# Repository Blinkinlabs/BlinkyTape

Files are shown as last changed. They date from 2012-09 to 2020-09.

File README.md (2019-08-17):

# BlinkyTape

BlinkyTape Photo

BlinkyTape is a one meter long, full-color light tape with 60 independent RGB LEDs controlled by our custom light processor. Power and communications are provided by a built-in micro-USB connector. An on-board button allows for simple interactions such as choosing between effects.

BlinkyTape is flexible, so you can easily integrate it into any shape your project needs. BlinkyTape also comes enclosed in weatherproof silicone, so it's suitable for outdoor use!

This GitHub repository contains the design files for the BlinkyTape controller, as well as the production test files.

More information about the BlinkyTape is available here: [http://blinkinlabs.com/blinkytape/](http://blinkinlabs.com/blinkytape/)

# I want one!

Cool! BlinkyTape is available in [our store](http://blinkinlabs.myshopify.com/products/blinkytape-basic), as well as through many fine distributors.

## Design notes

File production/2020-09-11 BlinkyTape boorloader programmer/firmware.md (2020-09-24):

Script for programming BlinkyTape firmware, using an Arduino as an ICSP.

Blinkytape firmware from PatternPaint: f31ba217fc51956d9388c4821eff59d83c6dc491
Bootloader from BlinkyTape: 968b2e03a9b3f808e57ad69727cdd8145f4d0792

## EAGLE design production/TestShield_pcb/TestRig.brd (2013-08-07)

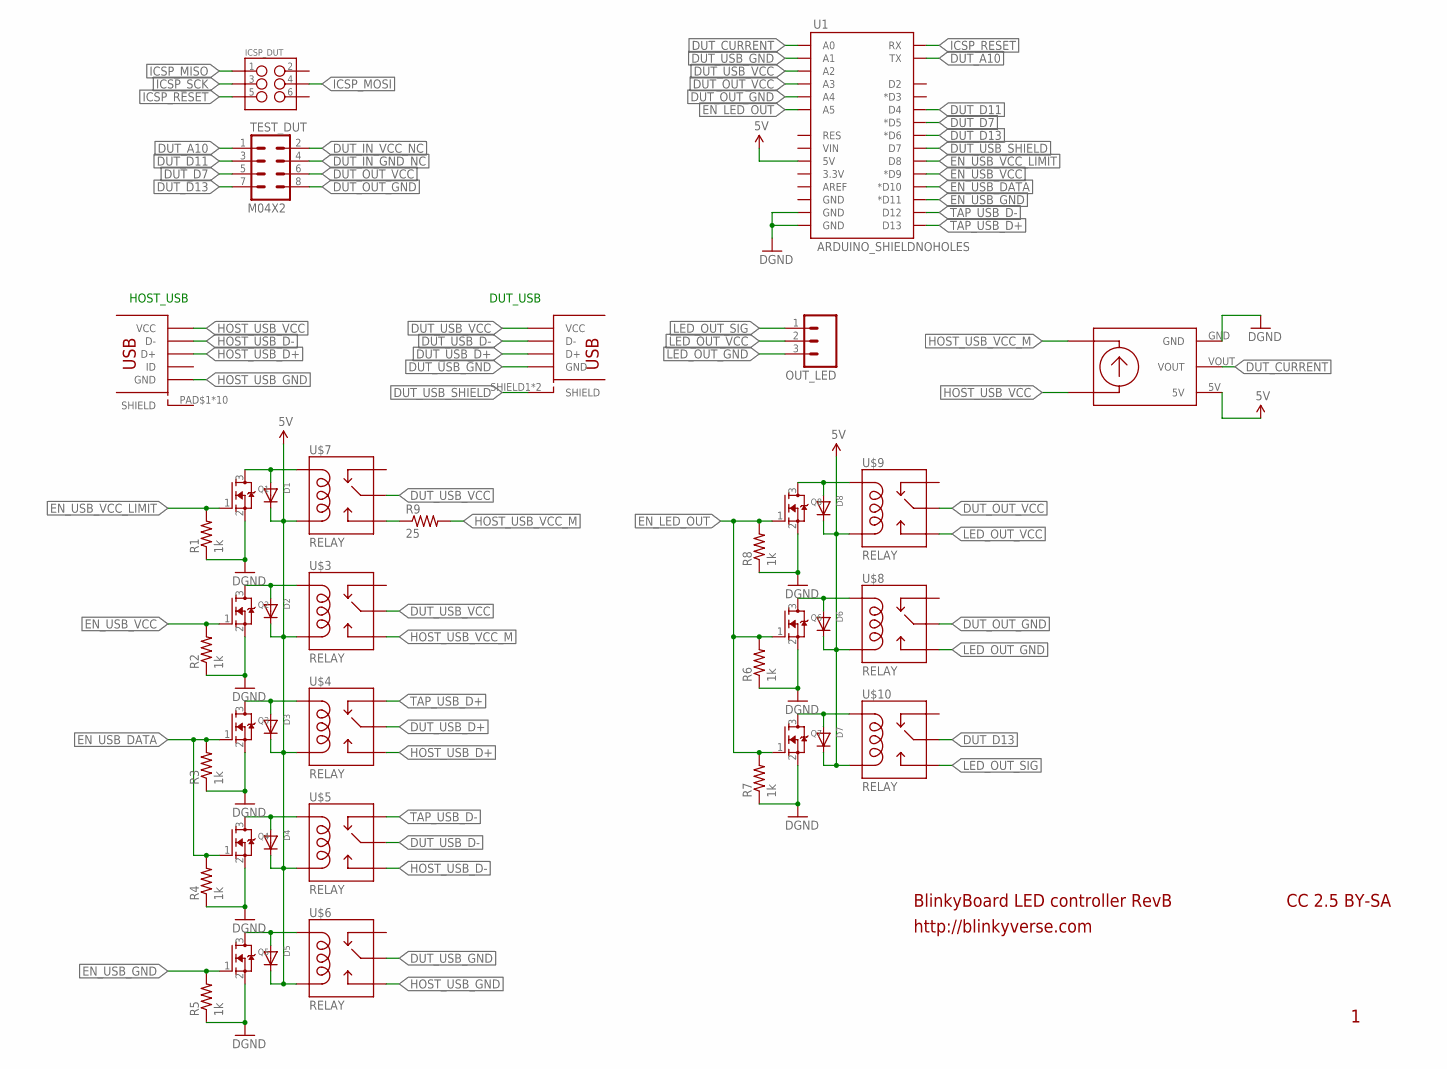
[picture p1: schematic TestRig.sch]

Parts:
D1, D2, D3, D4, D5, D6, D7, D8: DIODESOD-523; SOD-523
ICSP_DUT: M03X2NO_SILK; 2X3-NS
OUT_LED: M03PTH; 1X03
Q1, Q2, Q3, Q4, Q5, Q6, Q7, Q8: MOSFET-NREFLOW; SOT23
R1, R2, R3, R4, R5, R6, R7, R8: 1k; R0603
R9: 25; R1210
TEST_DUT: M04X2; 2X4
U1: ARDUINO_SHIELDNOHOLES; DUEMILANOVE_SHIELD_NOHOLES
U$1: USB; USB_A_FEMALE_NOSILK_SHIELD
U$2: MICRO_USBSMT+THRUHULE; MICRO_USB_FCI_THRUHOLE
U$3, U$4, U$5, U$6, U$7, U$8, U$9, U$10: RELAY; RELAY_HK23F-5V
U$11: SPARKFUN_ACS712

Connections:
5V: D1.K (C), D2.K (C), D3.K (C), D4.K (C), D5.K (C), D6.K (C), D7.K (C), D8.K (C), U1.5V, U$3.P$5 (COIL2), U$4.P$5 (COIL2), U$5.P$5 (COIL2), U$6.P$5 (COIL2), U$7.P$5 (COIL2), U$8.P$5 (COIL2), U$9.P$5 (COIL2), U$10.P$5 (COIL2), U$11.5V
DUT_A10: TEST_DUT.1, U1.TX
DUT_CURRENT: U1.A0, U$11.VOUT
DUT_D7: TEST_DUT.5, U1.D5 (*D5)
DUT_D11: TEST_DUT.3, U1.D4
DUT_D13: TEST_DUT.7, U1.D6 (*D6), U$10.P$1 (MAIN), U$10.P$6 (MAIN)
DUT_IN_GND_NC: TEST_DUT.4
DUT_IN_VCC_NC: TEST_DUT.2
DUT_OUT_GND: TEST_DUT.8, U1.A4, U$8.P$1 (MAIN), U$8.P$6 (MAIN)
DUT_OUT_VCC: TEST_DUT.6, U1.A3, U$9.P$1 (MAIN), U$9.P$6 (MAIN)
DUT_USB_D+: U$1.D+, U$4.P$1 (MAIN), U$4.P$6 (MAIN)
DUT_USB_D-: U$1.D-, U$5.P$1 (MAIN), U$5.P$6 (MAIN)
DUT_USB_GND: U1.A1, U$1.GND, U$6.P$1 (MAIN), U$6.P$6 (MAIN)
DUT_USB_SHIELD: U1.D7, U$1.SHIELD1 (SHIELD), U$1.SHIELD2 (SHIELD)
DUT_USB_VCC: U1.A2, U$1.VBUS (VCC), U$3.P$1 (MAIN), U$3.P$6 (MAIN), U$7.P$1 (MAIN), U$7.P$6 (MAIN)
EN_LED_OUT: Q6.1 (G), Q7.1 (G), Q8.1 (G), R6.2, R7.2, R8.2, U1.A5
EN_USB_DATA: Q3.1 (G), Q4.1 (G), R3.2, R4.2, U1.D10 (*D10)
EN_USB_GND: Q5.1 (G), R5.2, U1.D11 (*D11)
EN_USB_VCC: Q2.1 (G), R2.2, U1.D9 (*D9)
EN_USB_VCC_LIMIT: Q1.1 (G), R1.2, U1.D8
GND: Q1.2 (S), Q2.2 (S), Q3.2 (S), Q4.2 (S), Q5.2 (S), Q6.2 (S), Q7.2 (S), Q8.2 (S), R1.1, R2.1, R3.1, R4.1, R5.1, R6.1, R7.1, R8.1, U1.GND@0 (GND), U1.GND@1 (GND), U$11.GND
HOST_USB_D+: U$2.PIN$3 (D+), U$4.P$3 (NO)
HOST_USB_D-: U$2.PIN$2 (D-), U$5.P$3 (NO)
HOST_USB_GND: U$2.PIN$5 (GND), U$6.P$3 (NO)
HOST_USB_VCC: U$2.PIN$1 (VCC), U$11.IP-
HOST_USB_VCC_M: R9.2, U$3.P$3 (NO), U$11.IP+
ICSP_MISO: ICSP_DUT.1
ICSP_MOSI: ICSP_DUT.4
ICSP_RESET: ICSP_DUT.5, U1.RX
ICSP_SCK: ICSP_DUT.3
LED_OUT_GND: OUT_LED.3, U$8.P$3 (NO)
LED_OUT_SIG: OUT_LED.1, U$10.P$3 (NO)
LED_OUT_VCC: OUT_LED.2, U$9.P$3 (NO)
unnamed: R9.1, U$7.P$3 (NO)
unnamed: D1.A, Q1.3 (D), U$7.P$2 (COIL1)
unnamed: D2.A, Q2.3 (D), U$3.P$2 (COIL1)
unnamed: D3.A, Q3.3 (D), U$4.P$2 (COIL1)
unnamed: D4.A, Q4.3 (D), U$5.P$2 (COIL1)
unnamed: D5.A, Q5.3 (D), U$6.P$2 (COIL1)
unnamed: D6.A, Q6.3 (D), U$8.P$2 (COIL1)
unnamed: D7.A, Q7.3 (D), U$10.P$2 (COIL1)
unnamed: D8.A, Q8.3 (D), U$9.P$2 (COIL1)
TAP_USB_D+: U1.D13, U$4.P$4 (NC)
TAP_USB_D-: U1.D12, U$5.P$4 (NC)

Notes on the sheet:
BlinkyBoard LED controller RevB
http://blinkyverse.com
CC 2.5 BY-SA
DUT_USB
HOST_USB

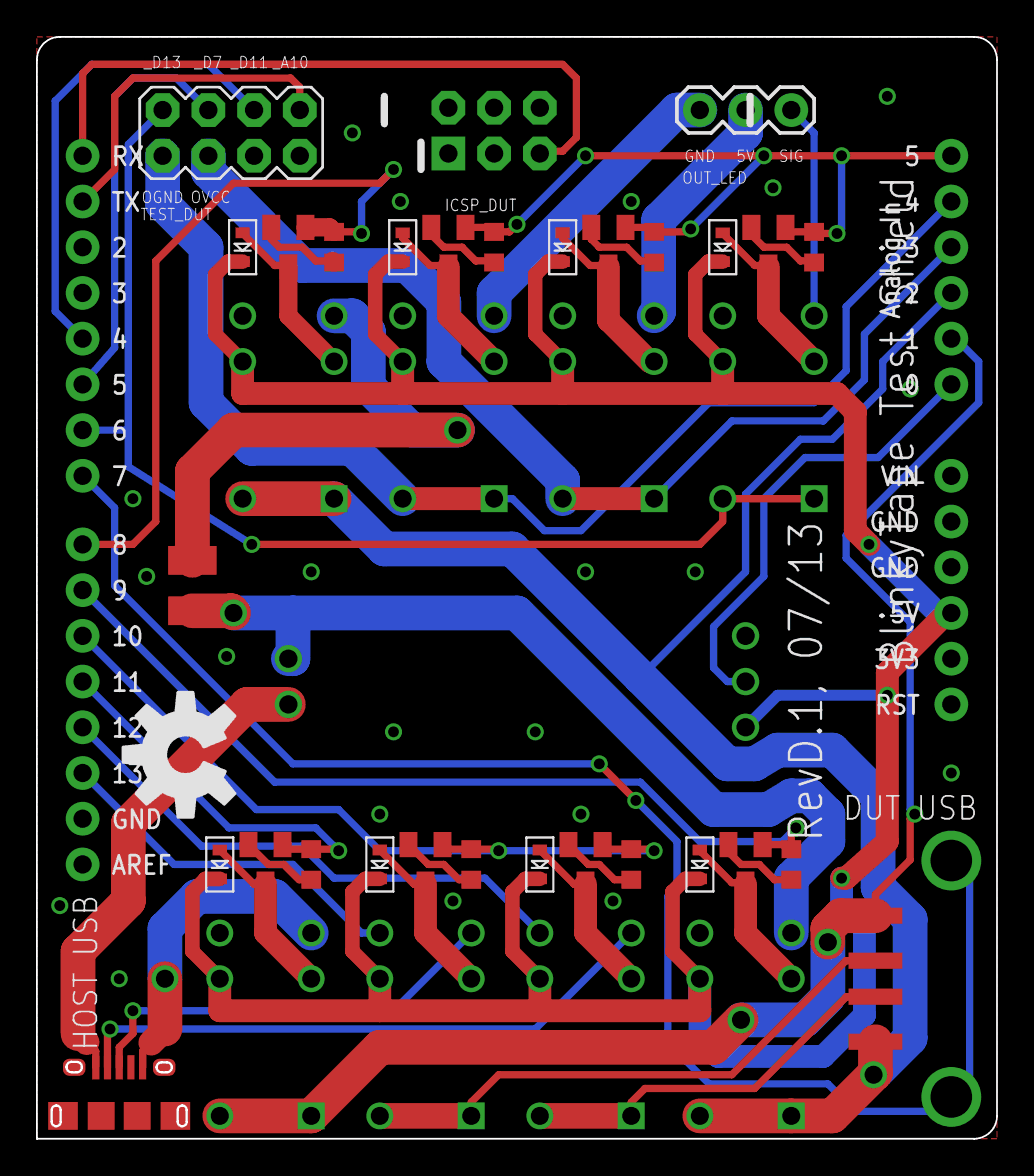
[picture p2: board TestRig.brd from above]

Board: 2 copper layers, 53.3 x 61.2 mm, 41 parts (0 on the bottom side), 39 nets.

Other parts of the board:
U$12: OSHW-LOGO-L

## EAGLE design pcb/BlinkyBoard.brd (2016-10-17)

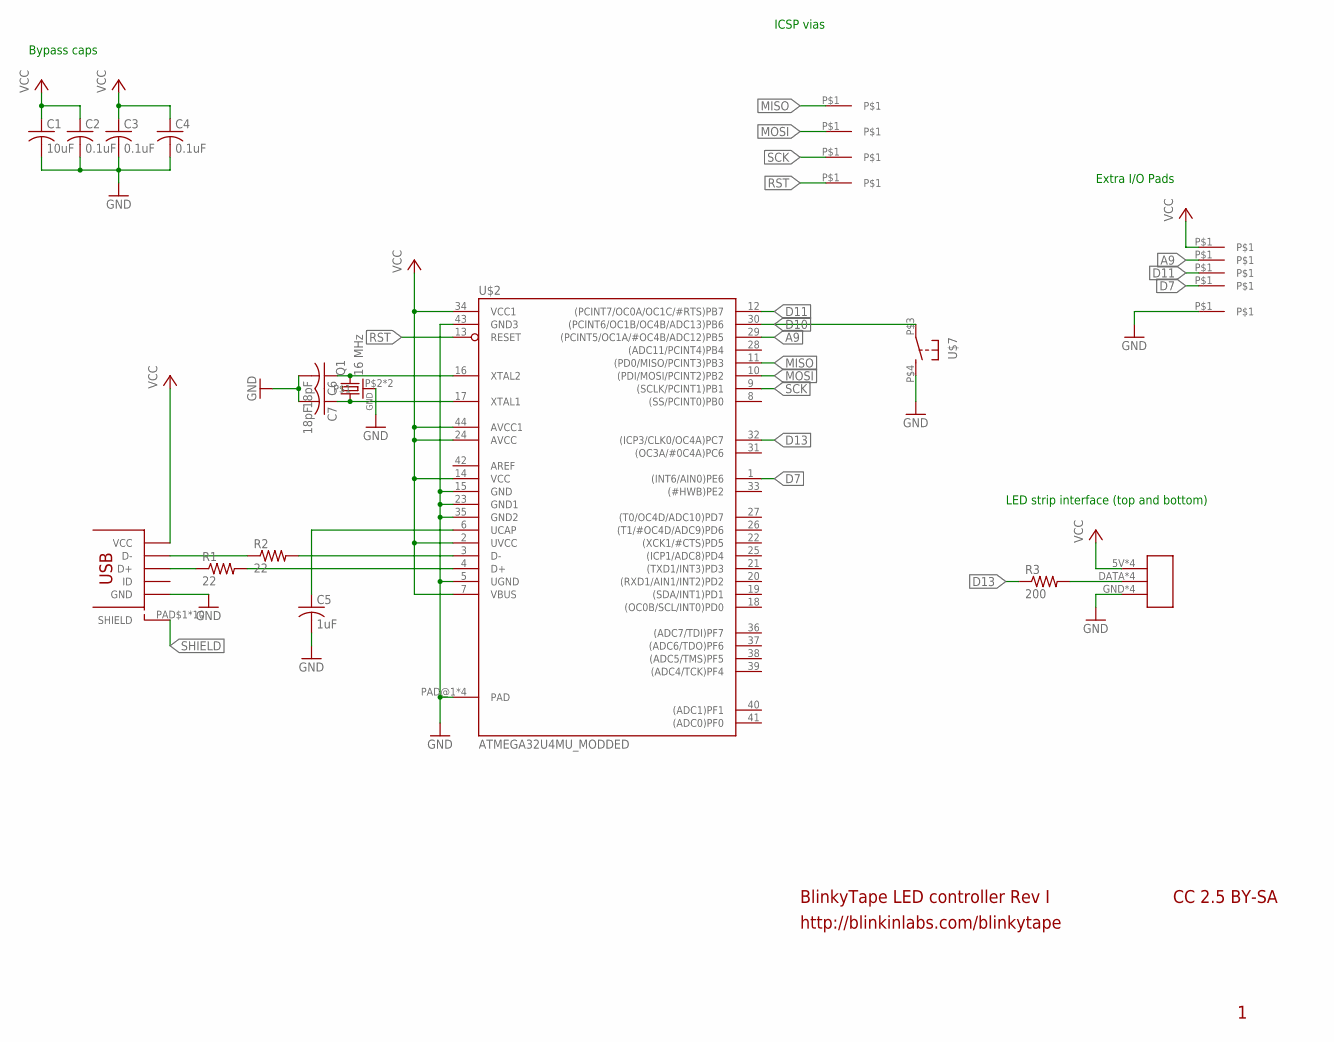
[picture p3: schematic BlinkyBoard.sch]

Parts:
C1: 10uF; C0603K
C2, C3, C4: 0.1uF; CAP_0402_KEMET_MEDIAN
C5: 1uF; CAP_0402_KEMET_MEDIAN
C6, C7: 18pF; CAP_0402_KEMET_MEDIAN
Q1: 16 MHz; CRSYTAL_2520
R1, R2: 22; RES_0402_KEMET_MEDIAN
R3: 200; RES_0402_KEMET_MEDIAN
U$1, U$3, U$5, U$6: TEST_PAD_SMT; TEST_PAD_1MM
U$2: ATMEGA32U4MU_MODDED; QFN44ML_7X7_LONGLEADS_MOD
U$4: USB_MICROSMT+THRUHULE; USB_MICRO_THRUHOLE
U$7: BUTTON_MOMENTARY; BUTTON_2P_SMD
U$9: WS2812B_CONNECTOR
U$10, U$11, U$12, U$13, U$14: TEST_PAD_SMT

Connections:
A9: U$2.29 ((PCINT5/OC1A/#OC4B/ADC12)PB5), U$11.P$1
AREF: U$2.42 (AREF)
D7: U$2.1 ((INT6/AIN0)PE6), U$10.P$1
D10: U$2.30 ((PCINT6/OC1B/OC4B/ADC13)PB6), U$7.P$3
D11: U$2.12 ((PCINT7/OC0A/OC1C/#RTS)PB7), U$14.P$1
D13: R3.P$1 (1), U$2.32 ((ICP3/CLK0/OC4A)PC7)
D+: R1.P$2 (2), U$2.4 (D+)
D+_IN: R1.P$1 (1), U$4.PIN$3 (D+)
D-: R2.P$2 (2), U$2.3 (D-)
D-_IN: R2.P$1 (1), U$4.PIN$2 (D-)
GND: C1.2, C2.P$2 (2), C3.P$2 (2), C4.P$2 (2), C5.P$2 (2), C6.P$2 (2), C7.P$2 (2), Q1.P$2, Q1.P$4, U$2.5 (UGND), U$2.15 (GND), U$2.23 (GND1), U$2.35 (GND2), U$2.43 (GND3), U$2.PAD@1 (PAD), U$2.PAD@4 (PAD), U$2.PAD@13 (PAD), U$2.PAD@16 (PAD), U$4.PIN$5 (GND), U$7.P$4 (S), U$9.GND, U$9.GND1 (GND), U$9.GND_1 (GND), U$9.GND_2 (GND), U$13.P$1
LED_DATA: R3.P$2 (2), U$9.DATA, U$9.DATA1 (DATA), U$9.DATA_1 (DATA), U$9.DATA_2 (DATA)
MISO: U$1.P$1, U$2.11 ((PD0/MISO/PCINT3)PB3)
MOSI: U$2.10 ((PDI/MOSI/PCINT2)PB2), U$3.P$1
unnamed: C5.P$1 (1), U$2.6 (UCAP)
unnamed: C6.P$1 (1), Q1.P$3 (2), U$2.16 (XTAL2)
unnamed: C7.P$1 (1), Q1.P$1 (1), U$2.17 (XTAL1)
RST: U$2.13 (RESET), U$6.P$1
SCK: U$2.9 ((SCLK/PCINT1)PB1), U$5.P$1
SHIELD: U$4.PAD$1 (SHIELD), U$4.PAD$2 (SHIELD), U$4.PAD$3 (SHIELD), U$4.PAD$4 (SHIELD), U$4.PAD$5 (SHIELD), U$4.PAD$6 (SHIELD), U$4.PAD$7 (SHIELD), U$4.PAD$8 (SHIELD), U$4.PAD$9 (SHIELD), U$4.PAD$10 (SHIELD)
VCC: C1.1, C2.P$1 (1), C3.P$1 (1), C4.P$1 (1), U$2.2 (UVCC), U$2.7 (VBUS), U$2.14 (VCC), U$2.24 (AVCC), U$2.34 (VCC1), U$2.44 (AVCC1), U$4.PIN$1 (VCC), U$9.5V, U$9.5V1 (5V), U$9.5V_1 (5V), U$9.5V_2 (5V), U$12.P$1

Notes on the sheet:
BlinkyTape LED controller Rev I
http://blinkinlabs.com/blinkytape
CC 2.5 BY-SA
Bypass caps
ICSP vias
Extra I/O Pads
LED strip interface (top and bottom)

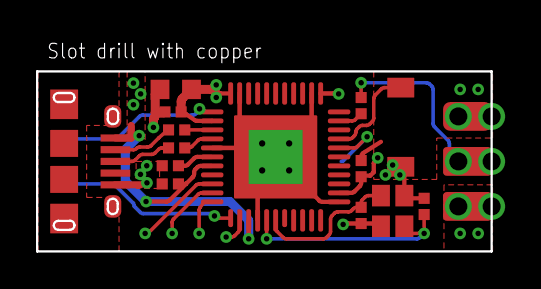
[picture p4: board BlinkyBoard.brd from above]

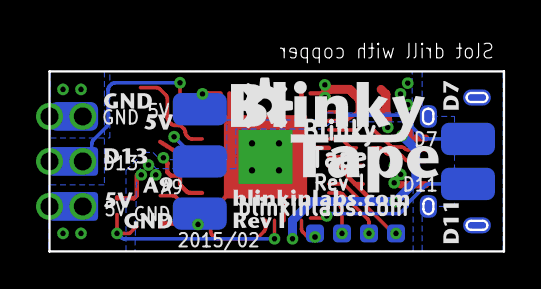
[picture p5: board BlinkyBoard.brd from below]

Board: 2 copper layers, 25.2 x 10.0 mm, 25 parts (11 on the bottom side), 20 nets.

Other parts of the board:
U$15: OSHW-LOGO-S

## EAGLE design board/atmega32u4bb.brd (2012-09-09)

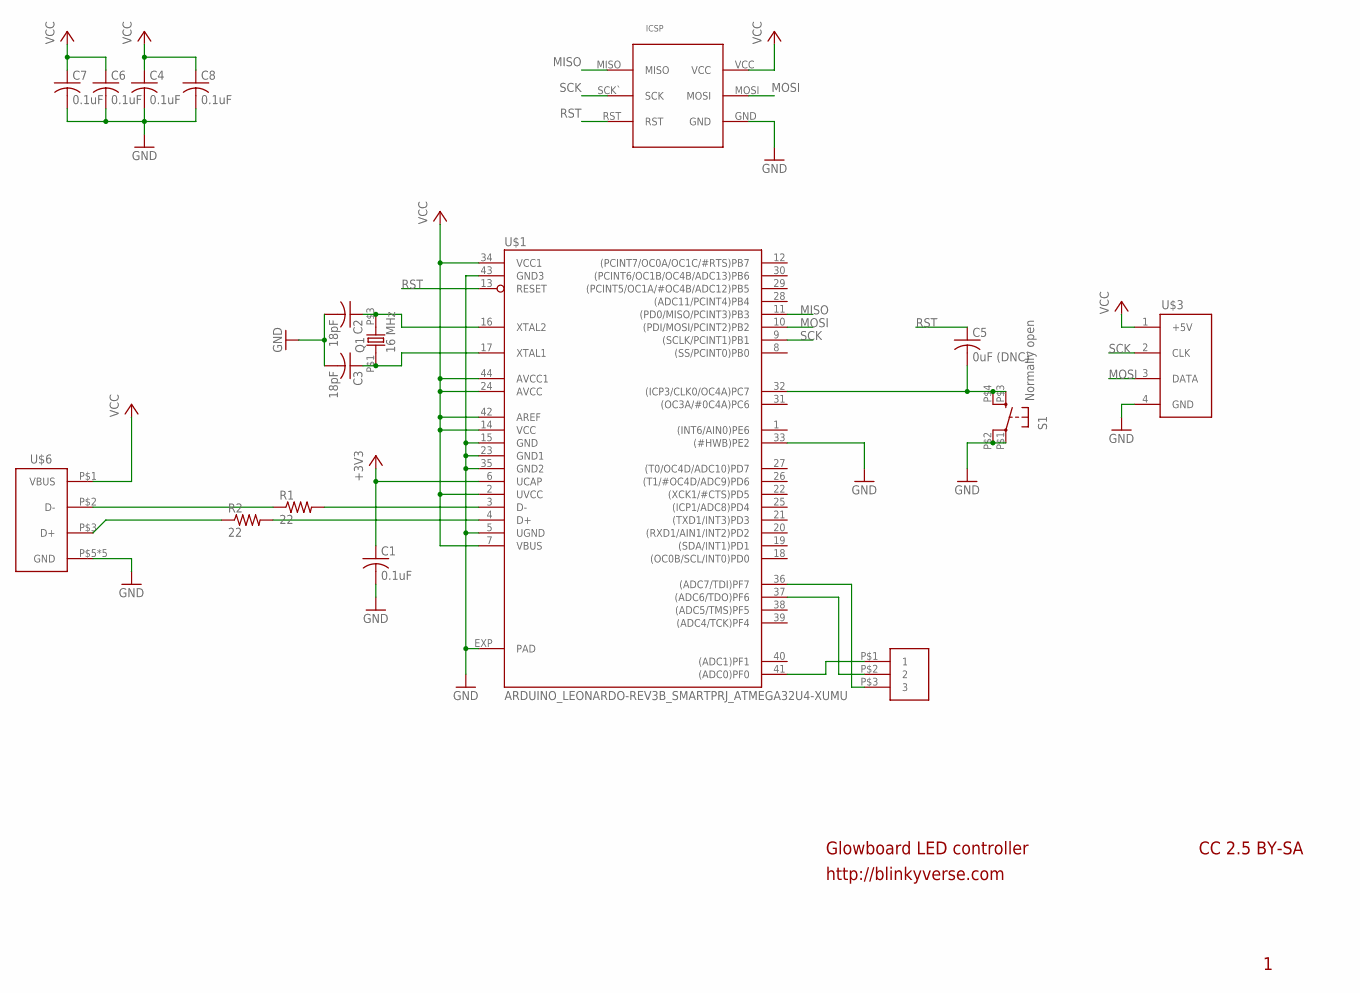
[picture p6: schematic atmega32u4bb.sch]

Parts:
C1, C4, C6, C7, C8: 0.1uF; C0805K
C2, C3: 18pF; C0805K
C5: 0uF (DNC); C0805K
Q1: 16 MHz; ABMM2_CRYSTAL
R1, R2: 22; R0805
S1: Normally open; GLOWBOARD_KMR211G_SWITCH
U$1: ARDUINO_LEONARDO-REV3B_SMARTPRJ_ATMEGA32U4-XUMU; ARDUINO_LEONARDO-REV3B_SMARTPRJ_QFN44ML7X7
U$3: GLOWBOARD_PAD_CONNECTION
U$4: GLOWBOARD_ICSP; GLOWBOARD_ICSP_PADS
U$5: GLOWBOARD_EXPANSION_HEADER
U$6: GLOWBOARD_MINI_USB; GLOWBOARD_MINI_USB_PADS

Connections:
+3V3: C1.1, U$1.6 (UCAP)
GND: C1.2, C2.2, C3.2, C4.2, C6.2, C7.2, C8.2, S1.P$1, S1.P$2 (P1), U$1.5 (UGND), U$1.15 (GND), U$1.23 (GND1), U$1.33 ((#HWB)PE2), U$1.35 (GND2), U$1.43 (GND3), U$1.EXP (PAD), U$3.4 (GND), U$4.GND, U$6.P$5 (GND), U$6.P$6 (GND), U$6.P$7 (GND), U$6.P$8 (GND), U$6.P$9 (GND)
MISO: U$1.11 ((PD0/MISO/PCINT3)PB3), U$4.MISO
MOSI: U$1.10 ((PDI/MOSI/PCINT2)PB2), U$3.3 (DATA), U$4.MOSI
unnamed: U$1.41 ((ADC0)PF0), U$5.P$1 (1)
unnamed: R2.1, U$6.P$3 (D+)
unnamed: R1.2, U$1.3 (D-)
unnamed: R2.2, U$1.4 (D+)
unnamed: R1.1, U$6.P$2 (D-)
unnamed: U$1.37 ((ADC6/TDO)PF6), U$5.P$2 (2)
unnamed: U$1.36 ((ADC7/TDI)PF7), U$5.P$3 (3)
unnamed: C2.1, Q1.P$3 (2), U$1.16 (XTAL2)
unnamed: C3.1, Q1.P$1 (1), U$1.17 (XTAL1)
unnamed: C5.2, S1.P$3 (S), S1.P$4 (S1), U$1.32 ((ICP3/CLK0/OC4A)PC7)
RST: C5.1, U$1.13 (RESET), U$4.RST
SCK: U$1.9 ((SCLK/PCINT1)PB1), U$3.2 (CLK), U$4.SCK` (SCK)
VCC: C4.1, C6.1, C7.1, C8.1, U$1.2 (UVCC), U$1.7 (VBUS), U$1.14 (VCC), U$1.24 (AVCC), U$1.34 (VCC1), U$1.42 (AREF), U$1.44 (AVCC1), U$3.1 (+5V), U$4.VCC, U$6.P$1 (VBUS)

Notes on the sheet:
Glowboard LED controller
http://blinkyverse.com
CC 2.5 BY-SA

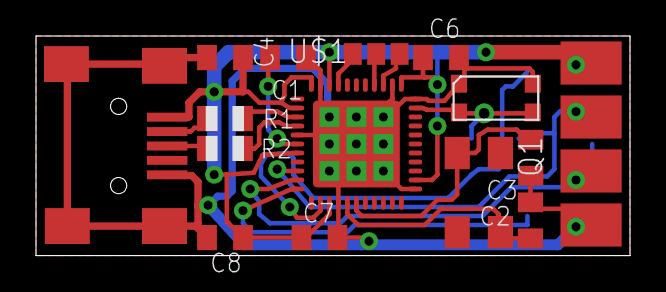
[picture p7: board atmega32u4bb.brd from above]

Board: 2 copper layers, 33.0 x 12.2 mm, 17 parts (1 on the bottom side), 17 nets.

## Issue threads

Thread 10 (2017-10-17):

External flash idea

dunk8888, 2017-10-17:
Hi,ime just wondering if its possible to have the blinky tape store the patterns into an external winbond flash unit,and if so would it be much work to implement ? Ime thinking this would be an idea many users would like,that way we can store many patterns to memory.Maybe a good idea to add an example for users who make there own BlinkTape version,ive made a few my self.

cibomahto, 2017-10-17:
We have something similar working in the EightByEight badge, which uses the flash chip built into the ESP8266 to store patterns:
https://github.com/Blinkinlabs/eightbyeight

The biggest issue with adding it to the current BlinkyTape is that the Atmega32u4 needs 5V to run at 16MHz speed, but basically all serial flash chips require a 3.3V interface. We've made some prototypes using an ARM part to replace the Atmega, and can fit the whole thing into the same size board as the blinkytape... but it still needs some development before we can release.

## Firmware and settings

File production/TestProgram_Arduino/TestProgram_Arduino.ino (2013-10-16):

// BlinkyTape Test Rig controller + ISP
// 
// 
// Based off of:
// 
// ArduinoISP version 04m3
// Copyright (c) 2008-2011 Randall Bohn
// If you require a license, see 
//     http://www.opensource.org/licenses/bsd-license.php
//
// This sketch turns the Arduino into a AVRISP
// using the following arduino pins:
//
// pin name:    BlinkyTape:
// slave reset: 0
// MOSI:        (MOSI, ICSP header)
// MISO:        (MISO, ICSP header)
// SCK:         (SCK, ICSP header)
//
// Put an LED (with resistor) on the following pins:
// X: Heartbeat   - shows the programmer is running=
// 0: Error       - Lights up if something goes wrong (use red if that makes sense)
// 1: Programming - In communication with the slave
//
// 6 August 2013 Matt Mets
// -Replace the analog current measurement with an INA219 courtesy Adafruit
// -Remove all LEDs (really no spare pins!)
// -move target reset pin to 0
//
// 7 July 2013 Matt Mets
// -Disable 'heartbeat' (no free pins!), move error, programming to pins 0 and 1.
// -Move target reset to pin 2.
// -Add 0x21 command for BlinkyTape Test rig functionality (!)
//
// 23 July 2011 Randall Bohn
// -Address Arduino issue 509 :: Portability of ArduinoISP
// http://code.google.com/p/arduino/issues/detail?id=509
//
// October 2010 by Randall Bohn
// - Write to EEPROM > 256 bytes
// - Better use of LEDs:
// -- Flash LED_PMODE on each flash commit
// -- Flash LED_PMODE while writing EEPROM (both give visual feedback of writing progress)
// - Light LED_ERR whenever we hit a STK_NOSYNC. Turn it off when back in sync.
// - Use pins_arduino.h (should also work on Arduino Mega)
//
// October 2009 by David A. Mellis
// - Added support for the read signature command
// 
// February 2009 by Randall Bohn
// - Added support for writing to EEPROM (what took so long?)
// Windows users should consider WinAVR's avrdude instead of the
// avrdude included with Arduino software.
//
// January 2008 by Randall Bohn
// - Thanks to Amplificar for helping me with the STK500 protocol
// - The AVRISP/STK500 (mk I) protocol is used in the arduino bootloader
// - The SPI functions herein were developed for the AVR910_ARD programmer 
// - More information at http://code.google.com/p/mega-isp

#include "pins_arduino.h"
#include <Wire.h>
#include <Adafruit_INA219.h>

Adafruit_INA219 ina219;

#define RESET     0

//#define LED_HB    0
//#define LED_ERR   0
//#define LED_PMODE 1
//#define PROG_FLICKER true

#define HWVER 2
#define SWMAJ 1
#define SWMIN 18

// STK Definitions
#define STK_OK      0x10
#define STK_FAILED  0x11
#define STK_UNKNOWN 0x12
#define STK_INSYNC  0x14
#define STK_NOSYNC  0x15
#define CRC_EOP     0x20 //ok it is a space...

void pulse(int pin, int times);

void setup() {
  Serial.begin(19200);
//  pinMode(LED_PMODE, OUTPUT);
//  pulse(LED_PMODE, 2);
//  pinMode(LED_ERR, OUTPUT);
//  pulse(LED_ERR, 2);
//  pinMode(LED_HB, OUTPUT);
//  pulse(LED_HB, 2);

  ina219.begin();
}

int error=0;
int pmode=0;
// address for reading and writing, set by 'U' command
int here;
uint8_t buff[256]; // global block storage

#define beget16(addr) (*addr * 256 + *(addr+1) )
typedef struct param {
  uint8_t devicecode;
  uint8_t revision;
  uint8_t progtype;
  uint8_t parmode;
  uint8_t polling;
  uint8_t selftimed;
  uint8_t lockbytes;
  uint8_t fusebytes;
  int flashpoll;
  int eeprompoll;
  int pagesize;
  int eepromsize;
  int flashsize;
} 
parameter;

parameter param;

//// this provides a heartbeat on pin 9, so you can tell the software is running.
//uint8_t hbval=128;
//int8_t hbdelta=8;
//void heartbeat() {
//  if (hbval > 192) hbdelta = -hbdelta;
//  if (hbval < 32) hbdelta = -hbdelta;
//  hbval += hbdelta;
//  analogWrite(LED_HB, hbval);
//  delay(20);
//}


void loop(void) {
//  // is pmode active?
//  if (pmode) digitalWrite(LED_PMODE, HIGH); 
//  else digitalWrite(LED_PMODE, LOW);
//  // is there an error?
//  if (error) digitalWrite(LED_ERR, HIGH); 
//  else digitalWrite(LED_ERR, LOW);

//  // light the heartbeat LED
//  heartbeat();
  if (Serial.available()) {
    avrisp();
  }
}

uint8_t getch() {
  while(!Serial.available());
  return Serial.read();
}
void fill(int n) {
  for (int x = 0; x < n; x++) {
    buff[x] = getch();
  }
}

#define PTIME 30
void pulse(int pin, int times) {
  do {
    digitalWrite(pin, HIGH);
    delay(PTIME);
    digitalWrite(pin, LOW);
    delay(PTIME);
  } 
  while (times--);
}

//void prog_lamp(int state) {
//  if (PROG_FLICKER)
//    digitalWrite(LED_PMODE, state);
//}

void spi_init() {
  uint8_t x;
  SPCR = 0x53;
  x=SPSR;
  x=SPDR;
}

void spi_wait() {
  do {
  } 
  while (!(SPSR & (1 << SPIF)));
}

uint8_t spi_send(uint8_t b) {
  uint8_t reply;
  SPDR=b;
  spi_wait();
  reply = SPDR;
  return reply;
}

uint8_t spi_transaction(uint8_t a, uint8_t b, uint8_t c, uint8_t d) {
  uint8_t n;
  spi_send(a); 
  n=spi_send(b);
  //if (n != a) error = -1;
  n=spi_send(c);
  return spi_send(d);
}

void empty_reply() {
  if (CRC_EOP == getch()) {
    Serial.print((char)STK_INSYNC);
    Serial.print((char)STK_OK);
  } 
  else {
    error++;
    Serial.print((char)STK_NOSYNC);
  }
}

void breply(uint8_t b) {
  if (CRC_EOP == getch()) {
    Serial.print((char)STK_INSYNC);
    Serial.print((char)b);
    Serial.print((char)STK_OK);
  } 
  else {
    error++;
    Serial.print((char)STK_NOSYNC);
  }
}

void get_version(uint8_t c) {
  switch(c) {
  case 0x80:
    breply(HWVER);
    break;
  case 0x81:
    breply(SWMAJ);
    break;
  case 0x82:
    breply(SWMIN);
    break;
  case 0x93:
    breply('S'); // serial programmer
    break;
  default:
    breply(0);
  }
}

void set_parameters() {
  // call this after reading paramter packet into buff[]
  param.devicecode = buff[0];
  param.revision   = buff[1];
  param.progtype   = buff[2];
  param.parmode    = buff[3];
  param.polling    = buff[4];
  param.selftimed  = buff[5];
  param.lockbytes  = buff[6];
  param.fusebytes  = buff[7];
  param.flashpoll  = buff[8]; 
  // ignore buff[9] (= buff[8])
  // following are 16 bits (big endian)
  param.eeprompoll = beget16(&buff[10]);
  param.pagesize   = beget16(&buff[12]);
  param.eepromsize = beget16(&buff[14]);

  // 32 bits flashsize (big endian)
  param.flashsize = buff[16] * 0x01000000
    + buff[17] * 0x00010000
    + buff[18] * 0x00000100
    + buff[19];

}

void start_pmode() {
  spi_init();
  // following delays may not work on all targets...
  pinMode(RESET, OUTPUT);
  digitalWrite(RESET, HIGH);
  pinMode(SCK, OUTPUT);
  digitalWrite(SCK, LOW);
  delay(50);
  digitalWrite(RESET, LOW);
  delay(50);
  pinMode(MISO, INPUT);
  pinMode(MOSI, OUTPUT);
  spi_transaction(0xAC, 0x53, 0x00, 0x00);
  pmode = 1;
}

void end_pmode() {
  pinMode(MISO, INPUT);
  pinMode(MOSI, INPUT);
  pinMode(SCK, INPUT);
  pinMode(RESET, INPUT);
  pmode = 0;
}

void universal() {
  int w;
  uint8_t ch;

  fill(4);
  ch = spi_transaction(buff[0], buff[1], buff[2], buff[3]);
  breply(ch);
}

void flash(uint8_t hilo, int addr, uint8_t data) {
  spi_transaction(0x40+8*hilo, 
  addr>>8 & 0xFF, 
  addr & 0xFF,
  data);
}
void commit(int addr) {
//  if (PROG_FLICKER) prog_lamp(LOW);
  spi_transaction(0x4C, (addr >> 8) & 0xFF, addr & 0xFF, 0);
//  if (PROG_FLICKER) {
//    delay(PTIME);
//    prog_lamp(HIGH);
//  }
}

//#define _current_page(x) (here & 0xFFFFE0)
int current_page(int addr) {
  if (param.pagesize == 32)  return here & 0xFFFFFFF0;
  if (param.pagesize == 64)  return here & 0xFFFFFFE0;
  if (param.pagesize == 128) return here & 0xFFFFFFC0;
  if (param.pagesize == 256) return here & 0xFFFFFF80;
  return here;
}


void write_flash(int length) {
  fill(length);
  if (CRC_EOP == getch()) {
    Serial.print((char) STK_INSYNC);
    Serial.print((char) write_flash_pages(length));
  } 
  else {
    error++;
    Serial.print((char) STK_NOSYNC);
  }
}

uint8_t write_flash_pages(int length) {
  int x = 0;
  int page = current_page(here);
  while (x < length) {
    if (page != current_page(here)) {
      commit(page);
      page = current_page(here);
    }
    flash(LOW, here, buff[x++]);
    flash(HIGH, here, buff[x++]);
    here++;
  }

  commit(page);

  return STK_OK;
}

#define EECHUNK (32)
uint8_t write_eeprom(int length) {
  // here is a word address, get the byte address
  int start = here * 2;
  int remaining = length;
  if (length > param.eepromsize) {
    error++;
    return STK_FAILED;
  }
  while (remaining > EECHUNK) {
    write_eeprom_chunk(start, EECHUNK);
    start += EECHUNK;
    remaining -= EECHUNK;
  }
  write_eeprom_chunk(start, remaining);
  return STK_OK;
}
// write (length) bytes, (start) is a byte address
uint8_t write_eeprom_chunk(int start, int length) {
  // this writes byte-by-byte,
  // page writing may be faster (4 bytes at a time)
  fill(length);
//  prog_lamp(LOW);
  for (int x = 0; x < length; x++) {
    int addr = start+x;
    spi_transaction(0xC0, (addr>>8) & 0xFF, addr & 0xFF, buff[x]);
    delay(45);
  }
//  prog_lamp(HIGH); 
  return STK_OK;
}

void program_page() {
  char result = (char) STK_FAILED;
  int length = 256 * getch();
  length += getch();
  char memtype = getch();
  // flash memory @here, (length) bytes
  if (memtype == 'F') {
    write_flash(length);
    return;
  }
  if (memtype == 'E') {
    result = (char)write_eeprom(length);
    if (CRC_EOP == getch()) {
      Serial.print((char) STK_INSYNC);
      Serial.print(result);
    } 
    else {
      error++;
      Serial.print((char) STK_NOSYNC);
    }
    return;
  }
  Serial.print((char)STK_FAILED);
  return;
}

uint8_t flash_read(uint8_t hilo, int addr) {
  return spi_transaction(0x20 + hilo * 8,
  (addr >> 8) & 0xFF,
  addr & 0xFF,
  0);
}

char flash_read_page(int length) {
  for (int x = 0; x < length; x+=2) {
    uint8_t low = flash_read(LOW, here);
    Serial.print((char) low);
    uint8_t high = flash_read(HIGH, here);
    Serial.print((char) high);
    here++;
  }
  return STK_OK;
}

char eeprom_read_page(int length) {
  // here again we have a word address
  int start = here * 2;
  for (int x = 0; x < length; x++) {
    int addr = start + x;
    uint8_t ee = spi_transaction(0xA0, (addr >> 8) & 0xFF, addr & 0xFF, 0xFF);
    Serial.print((char) ee);
  }
  return STK_OK;
}

void read_page() {
  char result = (char)STK_FAILED;
  int length = 256 * getch();
  length += getch();
  char memtype = getch();
  if (CRC_EOP != getch()) {
    error++;
    Serial.print((char) STK_NOSYNC);
    return;
  }
  Serial.print((char) STK_INSYNC);
  if (memtype == 'F') result = flash_read_page(length);
  if (memtype == 'E') result = eeprom_read_page(length);
  Serial.print(result);
  return;
}

void read_signature() {
  if (CRC_EOP != getch()) {
    error++;
    Serial.print((char) STK_NOSYNC);
    return;
  }
  Serial.print((char) STK_INSYNC);
  uint8_t high = spi_transaction(0x30, 0x00, 0x00, 0x00);
  Serial.print((char) high);
  uint8_t middle = spi_transaction(0x30, 0x00, 0x01, 0x00);
  Serial.print((char) middle);
  uint8_t low = spi_transaction(0x30, 0x00, 0x02, 0x00);
  Serial.print((char) low);
  Serial.print((char) STK_OK);
}
//////////////////////////////////////////
//////////////////////////////////////////


uint8_t versionNumber = 1;  // Simple I/O controller for use as a test rig

//// Mode averaging code from here:
//// http://www.elcojacobs.com/eleminating-noise-from-sensor-readings-on-arduino-with-digital-filtering/
//#define NUM_READS 500
//#define NUM_MODE_SAMPLES 50
//float readTemperature(int sensorpin){
//   // read multiple values and sort them to take the mode
//   int sortedValues[NUM_READS];
//   for(int i=0;i<NUM_READS;i++){
//     int value = analogRead(sensorpin);
//     int j;
//     if(value<sortedValues[0] || i==0){
//        j=0; //insert at first position
//     }
//     else{
//       for(j=1;j<i;j++){
//          if(sortedValues[j-1]<=value && sortedValues[j]>=value){
//            // j is insert position
//            break;
//          }
//       }
//     }
//     for(int k=i;k>j;k--){
//       // move all values higher than current reading up one position
//       sortedValues[k]=sortedValues[k-1];
//     }
//     sortedValues[j]=value; //insert current reading
//   }
//   
//   //return scaled mode of NUM_MODE_SAMPLES values
//   float returnval = 0;
//   for(int i=NUM_READS/2-NUM_MODE_SAMPLES/2;i<(NUM_READS/2+NUM_MODE_SAMPLES/2);i++){
//     returnval += sortedValues[i];
//   }
//   returnval = returnval/(NUM_MODE_SAMPLES);
//   
//   return returnval;
//}

void testRigCommand(uint8_t command, uint8_t channel) {
// Command descriptions:
// v: give the version (send vv)
// m: measure an analog channel
// r: read a digital channel
// o: set a digital channel to output
// i: set a digital channel to input without a pullup
// p: set a digital channel to input with a pullup
// h: set a digital channel output high
// l: set a digital channel output low

  switch(command) {
    case 'v':
      breply(versionNumber);
      break;
    case 'm':
      {
        // Convert a float into an integer, but with the decimal place shifted one digit to the right
//        int current = 0;
//        int current = readTemperature(channel)*10;
        int current = int(ina219.getCurrent_mA());
        
        if (CRC_EOP == getch()) {
          Serial.print((char)STK_INSYNC);
          Serial.print((char)((current >> 8) & 0xFF));
          Serial.print((char)(current & 0xFF));
          Serial.print((char)STK_OK);
        } 
        else {
          error++;
          Serial.print((char)STK_NOSYNC);
        }
      }
      break;
    case 'r':
      breply(digitalRead(channel));
      break;
    case 'o':
      pinMode(channel, OUTPUT);
      empty_reply();
      break;
    case 'i':
      pinMode(channel, INPUT);
      empty_reply();
      break;
    case 'p':
      pinMode(channel, INPUT_PULLUP);
      empty_reply();
      break;
    case 'h':
      digitalWrite(channel, HIGH);
      empty_reply();
      break;
    case 'l':
      digitalWrite(channel, LOW);
      empty_reply();
      break;
  }
}


////////////////////////////////////
////////////////////////////////////
int avrisp() { 
  uint8_t data, low, high;
  uint8_t ch = getch();
  switch (ch) {
  case '0': //0x30 signon
    error = 0;
    empty_reply();
    break;
  case '1': //0x31
    if (getch() == CRC_EOP) {
      Serial.print((char) STK_INSYNC);
      Serial.print("AVR ISP");
      Serial.print((char) STK_OK);
    }
    break;
  case 'A': //0x41
    get_version(getch());
    break;
  case 'B': //0x42
    fill(20);
    set_parameters();
    empty_reply();
    break;
  case 'E': //0x45 extended parameters - ignore for now
    fill(5);
    empty_reply();
    break;

  case 'P': //0x50
    start_pmode();
    empty_reply();
    break;
  case 'U': //0x55 set address (word)
    here = getch();
    here += 256 * getch();
    empty_reply();
    break;

  case 0x60: //STK_PROG_FLASH
    low = getch();
    high = getch();
    empty_reply();
    break;
  case 0x61: //STK_PROG_DATA
    data = getch();
    empty_reply();
    break;

  case 0x64: //STK_PROG_PAGE
    program_page();
    break;

  case 0x74: //STK_READ_PAGE 't'
    read_page();    
    break;

  case 'V': //0x56
    universal();
    break;
  case 'Q': //0x51
    error=0;
    end_pmode();
    empty_reply();
    break;

  case 0x75: //STK_READ_SIGN 'u'
    read_signature();
    break;

  case 0x21: // BlinkyTape Test rig command
    data = getch();
    low = getch();
    testRigCommand(data, low);
    break;

    // expecting a command, not CRC_EOP
    // this is how we can get back in sync
  case CRC_EOP:
    error++;
    Serial.print((char) STK_NOSYNC);
    break;

    // anything else we will return STK_UNKNOWN
  default:
    error++;
    if (CRC_EOP == getch()) 
      Serial.print((char)STK_UNKNOWN);
    else
      Serial.print((char)STK_NOSYNC);
  }
}

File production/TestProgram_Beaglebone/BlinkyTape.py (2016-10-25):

"""BlinkyTape Python communication library.

  This code assumes stock serialLoop() in the firmware.

  Commands are issued in 3-byte blocks, with pixel data
  encoded in RGB triplets in range 0-254, sent sequentially
  and a triplet ending with a 255 causes the accumulated pixel
  data to display (a show command).

  Note that with the stock firmware changing the maximum brightness
  over serial communication is impossible.
"""

import serial


class BlinkyTape(object):
    def __init__(self, port, ledCount=60, buffered=True):
        """Creates a BlinkyTape object and opens the port.

        Parameters:
          port
            Required, port name as accepted by PySerial library:
            http://pyserial.sourceforge.net/pyserial_api.html#serial.Serial
            It is the same port name that is used in Arduino IDE.
            Ex.: COM5 (Windows), /dev/ttyACM0 (Linux).
          ledCount
            Optional, total number of LEDs to work with,
            defaults to 60 LEDs. The limit is enforced and an
            attempt to send more pixel data will throw an exception.
          buffered
            Optional, enabled by default. If enabled, will buffer
            pixel data until a show command is issued. If disabled,
            the data will be sent in byte triplets as expected by firmware,
            with immediate flush of the serial buffers (slower).

        """
        self.port = port
        self.ledCount = ledCount
        self.position = 0
        self.buffered = buffered
        self.buf = ""
        self.serial = serial.Serial(port, 115200)
        self.show()  # Flush any incomplete data

    def send_list(self, colors):
        if len(colors) > self.ledCount:
            raise RuntimeError("Attempting to set pixel outside range!")
        for r, g, b in colors:
            self.sendPixel(r, g, b)
        self.show()

    def send_list(self, colors):
        data = ""
        for r, g, b in colors:
            if r >= 255:
                r = 254
            if g >= 255:
                g = 254
            if b >= 255:
                b = 254
            data += chr(r) + chr(g) + chr(b)
        self.serial.write(data)
        self.show()

    def sendPixel(self, r, g, b):
        """Sends the next pixel data triplet in RGB format.

        Values are clamped to 0-254 automatically.

        Throws a RuntimeException if [ledCount] pixels are already set.
        """
        data = ""
        if r < 0:
            r = 0
        if g < 0:
            g = 0
        if b < 0:
            b = 0
        if r >= 255:
            r = 254
        if g >= 255:
            g = 254
        if b >= 255:
            b = 254
        data = chr(r) + chr(g) + chr(b)
        if self.position < self.ledCount:
            if self.buffered:
                self.buf += data
            else:
                self.serial.write(data)
                self.serial.flush()
            self.position += 1
        else:
            raise RuntimeError("Attempting to set pixel outside range!")

    def show(self):
        """Sends the command(s) to display all accumulated pixel data.

        Resets the next pixel position to 0, flushes the serial buffer,
        and discards any accumulated responses from BlinkyTape.
        """
        control = chr(0) + chr(0) + chr(255)
        if self.buffered:
            self.serial.write(self.buf + control)
            self.buf = ""
        else:
            self.serial.write(control)
        self.serial.flush()
        self.serial.flushInput()  # Clear responses from BlinkyTape, if any
        self.position = 0

    def displayColor(self, r, g, b):
        """Fills [ledCount] pixels with RGB color and shows it."""
        for i in range(0, self.ledCount):
            self.sendPixel(r, g, b)
        self.show()

    def resetToBootloader(self):
        """Initiates a reset on BlinkyTape.

        Note that it will be disconnected.
        """
        self.serial.setBaudrate(1200)
        self.close()

    def close(self):
        """Safely closes the serial port."""
        self.serial.close()


# Example code

if __name__ == "__main__":

    import glob
    import optparse

    parser = optparse.OptionParser()
    parser.add_option("-p", "--port", dest="portname",
                      help="serial port (ex: /dev/ttyUSB0)", default=None)
    (options, args) = parser.parse_args()

    if options.portname is not None:
        port = options.portname
    else:
        serialPorts = glob.glob("/dev/cu.usbmodem*")
        port = serialPorts[0]

    bt = BlinkyTape(port)

    while True:
        bt.displayColor(255, 0, 0)
        bt.displayColor(0, 255, 0)
        bt.displayColor(0, 0, 255)
        bt.displayColor(255, 255, 255)
        bt.displayColor(0, 0, 0)

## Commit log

2012-08-21 Add stripped down leonardo board.
    [Arduino_Leonardo-REV3b.brd, Arduino_Leonardo-REV3b.sch]
2012-09-06 Add board design based on Adafruit Atmega 32u4 breakout board
    [Arduino_Leonardo-REV3b.brd, Arduino_Leonardo-REV3b.sch, atmega32u4bb.brd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]
2012-09-06 Move firmware to c++_firmware, to prepare for Arduino firmware.
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2012-09-08 V1 board design
    [atmega32u4bb.brd, atmega32u4bb.sch]
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2012-09-08 Fix some errors
    [atmega32u4bb.brd, atmega32u4bb.sch]
2012-09-08 Passes DRC, add expansion header, move switch to non-reset pin.
    [atmega32u4bb.brd, atmega32u4bb.sch]
2012-09-09 Minor tweak
    [atmega32u4bb.brd]
2012-09-09 Board updated! Looks ok.
    [atmega32u4bb.brd, atmega32u4bb.sch]
2012-09-09 added bplace silks
    [atmega32u4bb.brd]
2012-09-10 Add silk, make ground trace wider, rename to BlinkyBoard
    [BlinkyBoard.brd, BlinkyBoard.sch]
2012-09-10 Resize drill holes to match imperial drills, drop flood fills on top and bottom.
    [BlinkyBoard.brd]
2012-09-10 Snap dimensions to inches
    [BlinkyBoard.brd]
2012-09-10 Remove all names/values
    [BlinkyBoard.brd]
2012-09-10 Hopefully Rev A!!
    [BlinkyBoard.brd, BlinkyBoard.sch]
2012-09-11 Add Rev A .1 release, the initial version did not include a board outline.
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2012-10-09 Add battery test script, and first r
    [first_run_output.csv]
2013-02-13 moved color loop to its own function, added 32 bit led array
2013-02-13 Clean up the arduino example a bit. Serial override mode exists now.
2013-03-25 Remove unused c++ examples, rename Arduino firmware to line up with other Blinkiverse projects
2013-03-25 Replace mini USB footprint with Micro USB, swap in 0603 components and smaller crystal, add ground plane to backside
    [BlinkyBoard.brd, BlinkyBoard.sch]
2013-03-25 Rename board directory to pcb, to line up with other blinkiverse projects. Drop obsolete files.
    [BlinkyBoard.brd, BlinkyBoard.sch]
2013-03-25 Move datasheets to a top-level directory, remove old board release files.
    [first_run_output.csv]
2013-03-26 Reduce topology
    [BlinkyBoard.brd]
2013-03-30 Reworked LED_AQI to work better
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2013-04-03 Changes to LPD8806 Python example lib
    * Push packets in GRB instead of RGB order
    * self.gamma no longer both a tuple and a method
    * allOn now turns LEDs on instead of off
2013-04-14 Switch to 2520 crystal, remove unused layers, rename components
    [BlinkyBoard.brd, BlinkyBoard.sch]
2013-04-14 Update 0402 resistor, add ICSP pads as tiny headers, make board smaller
    [BlinkyBoard.brd, BlinkyBoard.sch]
2013-04-15 Add chopped version of 32u4 package, for BB RevB
    [BlinkyBoard.brd, BlinkyBoard.sch]
2013-04-15 Add some copper pads for the expansion connector
    [BlinkyBoard.brd]
2013-04-15 Make the .35mm vias tented
    [BlinkyBoard.brd]
2013-04-15 Fuses are for suckers.
    [BlinkyBoard.brd, BlinkyBoard.sch]
2013-04-16 Board is routed! Now just add silk
    [BlinkyBoard.brd]
2013-04-16 Silks added, routing cleaned up on bottom. Ready for release?
    [BlinkyBoard.brd]
2013-04-16 Add janky file used to create the alignment stencil
    [BlinkyBoard_stencil.brd]
2013-04-16 Fix the stencil: use drill holes from Zach's library
    [BlinkyBoard_stencil.brd]
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2013-04-20 Added simple Button dimmer example
    * Uses Button lib: https://github.com/virgildisgr4ce/Button
    * Press dims by 25% until dark
    * Hold (1s) resets to 100% brightness
2013-04-20 Proper power-up/cool-down to seizure mode
    For some reason this is really fun.
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2013-04-29 Add discoparty_viz (used in ks video), led suspenders animation, and an update to the soundscarf
2013-05-13 Fix NeoPixel import for LEDspenders example
2013-05-23 PCB: replace smt USB connector with thru-hole version
    [BlinkyBoard.brd, BlinkyBoard.sch]
2013-05-24 Switch to thru-hole micro usb, add expansion pads on the bottom, make thermal vias on the processor smaller.
    [BlinkyBoard.brd, BlinkyBoard.sch]
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2013-05-24 Update board to RevC candidate (update silk)
    [BlinkyBoard.brd, BlinkyBoard_stencil.brd]
2013-05-24 Add test rig files
    [bb hand programmer.STL, test jig (needs chamfered edges).scad]
2013-05-25 Add Apache license file. We might switch to something else in the future (GPL?)
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2013-05-29 Add first piece of the test program: an n*n scanning system that can detect shorts (or opens) between the board I/O.
2013-06-07 Add BlinkyTile laser cutter designs
    [BlinkyTile.scad, frame-back.dxf, frame-bottom.dxf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]
2013-06-08 frame-leftright.dxf is obsolete
    [frame-leftright.dxf]
2013-06-20 Fix thru-hole micro usb pads, switch 10uF cap to 0603 package
    [BlinkyBoard.brd, BlinkyBoard.sch]
2013-06-20 Swap extra IO pads for ones that are actually Arduino pins, rename analog to A11
    [BlinkyBoard.brd, BlinkyBoard.sch]
2013-06-20 Almost have D7 squeezed in, clean up silk
    [BlinkyBoard.brd, BlinkyBoard.sch]
2013-06-20 RevD candidate- Move switch to D10 (for interrupt capability), then move analog input to A10 and LED_DATA to D13.
    [BlinkyBoard.brd, BlinkyBoard.sch]
2013-06-20 Fix copper planes under usb connector
    [BlinkyBoard.brd, BlinkyBoard.sch]
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2013-06-25 Reorganize test designs, add test card, fix silk on main PCBA
    [BlinkyBoard-testcard.brd, BlinkyBoard-testcard.sch, BlinkyBoard.brd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]
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2013-06-28 Add test shield design
    [TestRig.brd, TestRig.sch]
2013-06-29 RevD of the test shield PCB
    [TestRig.brd, TestRig.sch]
2013-07-02 PCB design fix: add cream to all USB ground pads!
    [BlinkyBoard.brd, BlinkyBoard.sch]
2013-07-10 Add platform detection, so we can look for the right serial device on each platform
2013-07-12 Fix the test flow, prettify the output a bit
    [BlinkyTape.py, BlinkyTapeUnitTest.py, IcspUtils.py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]
2013-07-25 Minor updates to test rig
    [TestRig.brd, TestRig.sch]
2013-07-27 PCB: Make LED connector holes bigger as per Bunnie's suggestion. Move the BlinkyTape logo a bit.
    [BlinkyBoard.brd]
2013-08-02 Bugfix: fuse bits were not being programmed correctly.
    [IcspUtils.py, TestRig.py, test_bootloader.py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]
2013-08-07 Test rig update: programming, current measurement functional
    [TestRig.brd, TestRig.sch]
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2013-08-08 Add independent input tests, in lieu of short tests
    [BlinkyTape.py, Menu.py, TestRig.py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]
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2013-08-14 RevF release: modify pads to support WS2811B
    [BlinkyBoard.brd, BlinkyBoard.sch]
2013-08-21 Flip gnd/5v to match WS2812B strip.
    [BlinkyBoard.brd, BlinkyBoard.sch]
2013-09-02 Silkscreen fix: Analog is on A9, not A11!
    [BlinkyBoard.brd, BlinkyBoard.sch]
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2013-09-13 Update the production application to use the correct VID/PID
    [IcspUtils.py, TestRig.py, test_bootloader.py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]
2013-09-15 Modify DetectPlatform and RemoteArduino to work with FTDI-based Arduino on OS X
2013-09-15 Fix Arduino sketch for test board
    [TestProgram_Arduino.ino]
2013-09-15 Bring in most fixes to get the rig working on the factory floor.
    [test_functional.py]
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2013-10-08 Reorgainze, now that this repo only contains support for making the controller.
    [BlinkyBoard-testcard.brd, BlinkyBoard-testcard.sch, TestRig.brd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]
2013-10-16 Bugfixes for test rig filesystem issue, actual production version
    [Logger.py, test_functional.py, test_power_on.py]
2013-10-31 Add series resistor to the output data line, so it can be removed from the flex strip
    [BlinkyBoard.brd, BlinkyBoard.sch]
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2014-03-17 Add back LCD support, log avrdude issues, add init.d script for RasPi
    [IcspUtils.py, Menu.py, UserInterface.py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]
2014-03-17 Widen current limits for LED test, timing issue.
    [test_functional.py]
2014-03-19 Add updated production sketch; cycles through a couple patterns. Is broken at the moment.
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2015-03-18 Remove old programming jig design
    [bb hand programmer.SLDPRT, bb hand programmer.STL]
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2015-03-18 Add untested wide version of board
    [BlinkyBoard_wide.brd, BlinkyBoard_wide.sch]
2016-02-11 RevI PCB, improved component spacing and power routing
    [BlinkyBoard.brd, BlinkyBoard.sch]
2016-02-11 Remove some excess noise on the silk
    [BlinkyBoard.brd]
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2016-10-17 Fix output resistor value
    [BlinkyBoard.brd, BlinkyBoard.sch]
2016-10-25 Remove outdated example
    [BlinkyTile.scad, frame-back.dxf, frame-bottom.dxf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]
2016-10-25 Rearrange files
    [TestRig.brd, TestRig.sch]

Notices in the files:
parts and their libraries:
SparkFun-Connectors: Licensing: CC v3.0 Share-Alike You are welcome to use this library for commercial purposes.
